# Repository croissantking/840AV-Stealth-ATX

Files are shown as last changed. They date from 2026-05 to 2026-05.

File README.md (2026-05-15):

$\color{#FF0000}{IMPORTANT!}$ <b>Working with switching power supplies involves dangerous, potentially lethal voltages, even when the device is disconnected from mains power. Improper handling can result in serious injury or death.

This repository provides Gerber files and related materials in good faith to the Macintosh hobby community, without any warranty or guarantee of any kind, including safety, reliability, or fitness for any particular purpose.

This design has not been safety-certified or fully validated under all operating conditions.

By using this material, you explicitly agree that:

- You assume all risk and responsibility for construction, modification, and use
- The author is not liable for any damage, injury, or death resulting from use or misuse
- You will only proceed if you are qualified and understand high-voltage electronics safety

If you are not experienced with mains-powered or high-voltage electronics, do not attempt to use this material.</b>

<b>Introduction and Outline</b>
-
This two-layer 'ATX Conversion Board' PCB enables you rebuild a failed Delta SMP-220DB Power Supply, found in your Apple Macintosh Quadra 800/840AV or Power Macintosh 8100, with easily obtainable second hand parts.

Front

The PCB replicates the exact dimensions of the Delta's lower PCB, securing to the chassis just as the original. It's designed to have the internals of one of the following Seasonic-based ATX power supplies stood off above it as a mezzanine board:

- Antec EarthWatts EA-380 / EA-430 / EA-500 (without 'D' suffix)
- Seasonic SS-350ET / SS-400ET / SS-500ET (ES suffix also OK)
- Seasonic S12-II 500W

The PCBs in these PSUs are all the same and are labelled ATX400W REV:A5. Some of the components may be slightly different based on the output rating.

If you want, you can modify the Gerbers to fit the mounting locations of your own chosen PSU. You can also drill holes into the board but note that a new connection should be made to the ground plane from each of the new standoff locations if doing this.

The design reuses the Delta SMP-220DB AC inlet board, and replicates both the original monitor passthrough power relay and fan speed control logic for authentic behaviour.

The 20/24 pin ATX harness is intended to be cut short and looped into the +12V, GND, -12V, +5V, PS_ON and +5VSB vias seen at the top of the new PCB. This is so a soft power inverter can be integrated, and also allows the original modular Mac PSU connector to be fitted in its original location.

BOM
-
Please see <a href="https://github.com/croissantking/840AV-Stealth-ATX/blob/main/BOM.csv" target="_blank" rel="noopener noreferrer">BOM.csv</a> for a parts list.

A Digikey cart is available here: https://www.digikey.co.uk/en/mylists/list/5MLRWHWYBX

Ordering
-
Simply download the Gerbers.zip file and then upload this to JLCPCB. Pick and Place files are available for the SMD parts, if desired.

Assembly
-
Here are the steps needed to assemble your rebuilt power supply. Note that I'm working with a slightly different pre-release board layout.

key

Once you have the bare Conversion Board PCB in your hands, decide if you'll be populating the fan circuit and the CRT relay as shown in the key above. Both circuits are optional. If you are not populating the fan control circuit then your fan should be connected to the ATX PCB. The through hole parts should be taken from the original Delta PSU (apart from the fan header), while SMDs should be newly obtained.

To install the AC inlet connector, either re-use the one from the original PSU or purchase a new one.

Circuits2

In this corner you'll install the 22-way MiniFit Jr Connector (you can bring this from the old board or purchase new), trimming off the mounting flange on one side in order to make way for a metal standoff. You'll also install a small capacitor and inverter for the soft power circuit.



Detach this little washer-type part from the original PCB and solder it here.

populated

Now that the Conversion Board is populated you can fit the 4x standoffs. Place the ATX PCB on top and loosely screw it down with just the two standoffs marked '1' and '2' nearest the lower edge.



From the other side, you can start to trim the wires of your 20/24-pin ATX connector harness to the correct length to connect to the lower PCB. +12V, GND, -12V, +5V, PS_ON and +5VSB are needed; the rest can be shortened and insulated or desoldered as you wish. Hinge the ATX PCB upwards in order to get better access to solder.

You should cut back and insulate (or desolder) any drive connectors you don't need; the remaining ones will feed through the Delta housing circular cutout.



Here, all the connections have been successfully made, and the ATX PCB has been fully screwed down. 

live-neutral

Turn the assembly around again, and solder two short wires (live and neutral) from the Conversion Board to the ATX PCB. These should be at least 18AWG and preferably 16AWG.



The full assembly can now be installed in your Delta housing, and the AC inlet board plugged in to the Conversion Board.

$\color{#FF0000}{IMPORTANT!}$ The two large left-hand heatsinks on the ATX board have a high voltage when the unit is powered up (and for some time after power is disconnected) which will give you a nasty shock if you touch them. Please be extra careful.



Make sure to insulate the ferrite ring with kapton tape (or similar) so that it does not accidentally short out the exposed solder joints on the back of the inlet board.

fan-rewire

You can re-use the original 120mm fan or install a modern replacement (e.g. Noctua). In my build I opted to re-use the original but it needed a longer cable with a three-pin connector for my Conversion Board's new header. So I peeled back the sticker over the motor to expose the solder points and replace the cable.



The cable was now long enough to reach the new header on the Conversion Board, with plenty of slack for ease of installation.


Here is the PSU fully assembled and ready to use.

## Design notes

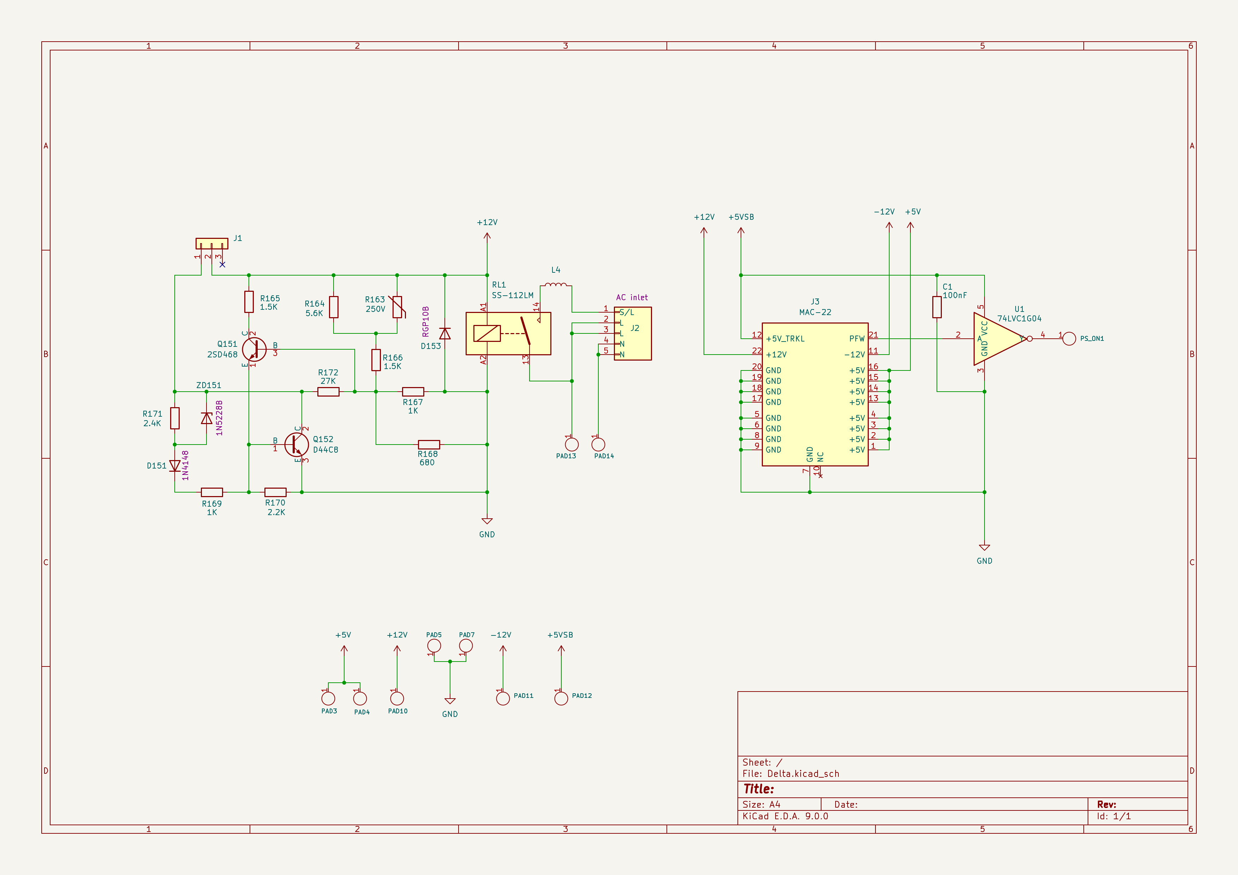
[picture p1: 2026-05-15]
Preview/Delta-schematics.jpg

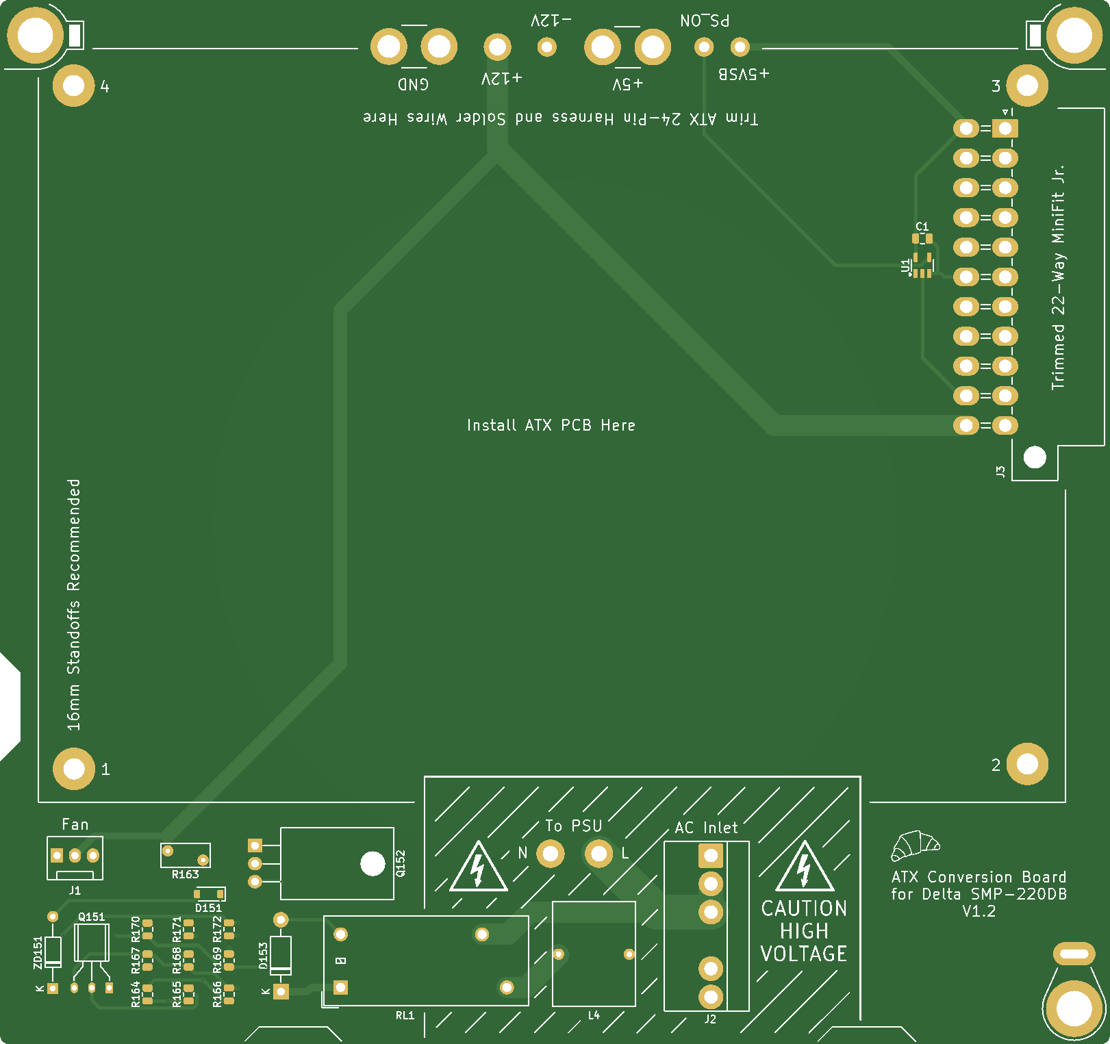
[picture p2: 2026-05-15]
Preview/Front.png

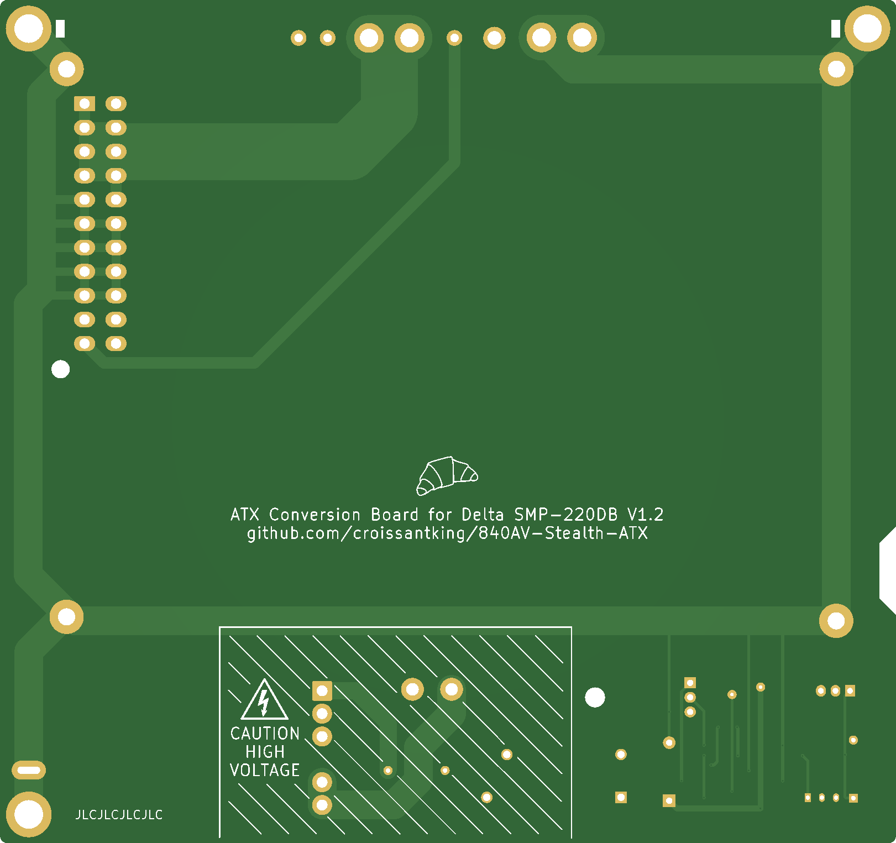
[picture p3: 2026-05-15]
Preview/Back.png

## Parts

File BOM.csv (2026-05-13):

Item | Qty | Reference(s) | Value | Size (Imperial) | P/N | URL
Capacitor | 1 | C1 | 100nF | 0805 | CC0805KRX7R9BB104 | https://www.digikey.co.uk/short/rhqt2bb8
Inverter | 1 | U1 | 74LVC1G04 | SOT-23-5 | SN74LVC1G04DBVR | https://www.digikey.co.uk/short/q94n5n4v
Varistor | 1 | R163 | 250V |  |  | Obsolete, reuse old part
Resistor | 1 | R164 | 5.6K | 0805 | RC0805FR-075K6L | https://www.digikey.co.uk/short/3hchtvn2
Resistor | 2 | R165, R166 | 1.5K | 0805 | RC0805FR-071K5L | https://www.digikey.co.uk/short/47733rr1
Resistor | 2 | R167, R169 | 1K | 0805 | RC0805FR-071KL | https://www.digikey.co.uk/short/3r7cmt8z
Resistor | 1 | R168 | 680 | 0805 | RC0805JR-07680RL | https://www.digikey.co.uk/short/p1r5pjzt
Resistor | 1 | R170 | 2.2K | 0805 | RC0805JR-072K2L | https://www.digikey.co.uk/short/30m97n75
Resistor | 1 | R171 | 2.4K | 0805 | RC0805JR-072K4L | https://www.digikey.co.uk/short/4pn84b8b
Resistor | 1 | R172 | 27K | 0805 | RC0805FR-0727KL | https://www.digikey.co.uk/short/m2709928
Relay | 1 | RL1 | OMIT-SS-112LM |  |  | Obsolete, reuse old part
Zener Diode | 1 | ZD151 | 1N5228B | DO-35 |  | https://www.digikey.co.uk/short/841nhv9d
Diode | 1 | D151 | 1N4148 | SOD-123 | 1N4148W-7-F | https://www.digikey.co.uk/short/0tb77nc3
Diode | 1 | D153 | RGP10B | DO-41 |  | https://www.digikey.co.uk/short/dnzptpbv
Transistor | 1 | Q151 | 2SD468 | TO-92 |  | Obsolete, reuse old part
Transistor | 1 | Q152 | D44C8 | TO-220 |  | Obsolete, reuse old part
Connector | 1 | J1 | Molex KK100, 6373 |  | 22-23-2033 | https://www.digikey.co.uk/short/rzfj2mbw
Connector | 1 | J2 | Molex KK396, 5273 |  | 09-65-2068 | https://www.digikey.co.uk/short/9mqpdqwd
Connector | 1 | J3 | Molex Mini-Fit Jr |  | 39-29-1227 | https://www.digikey.co.uk/short/t949vm2z
Inductor | 1 | L4 |  |  |  | Obsolete, reuse old part

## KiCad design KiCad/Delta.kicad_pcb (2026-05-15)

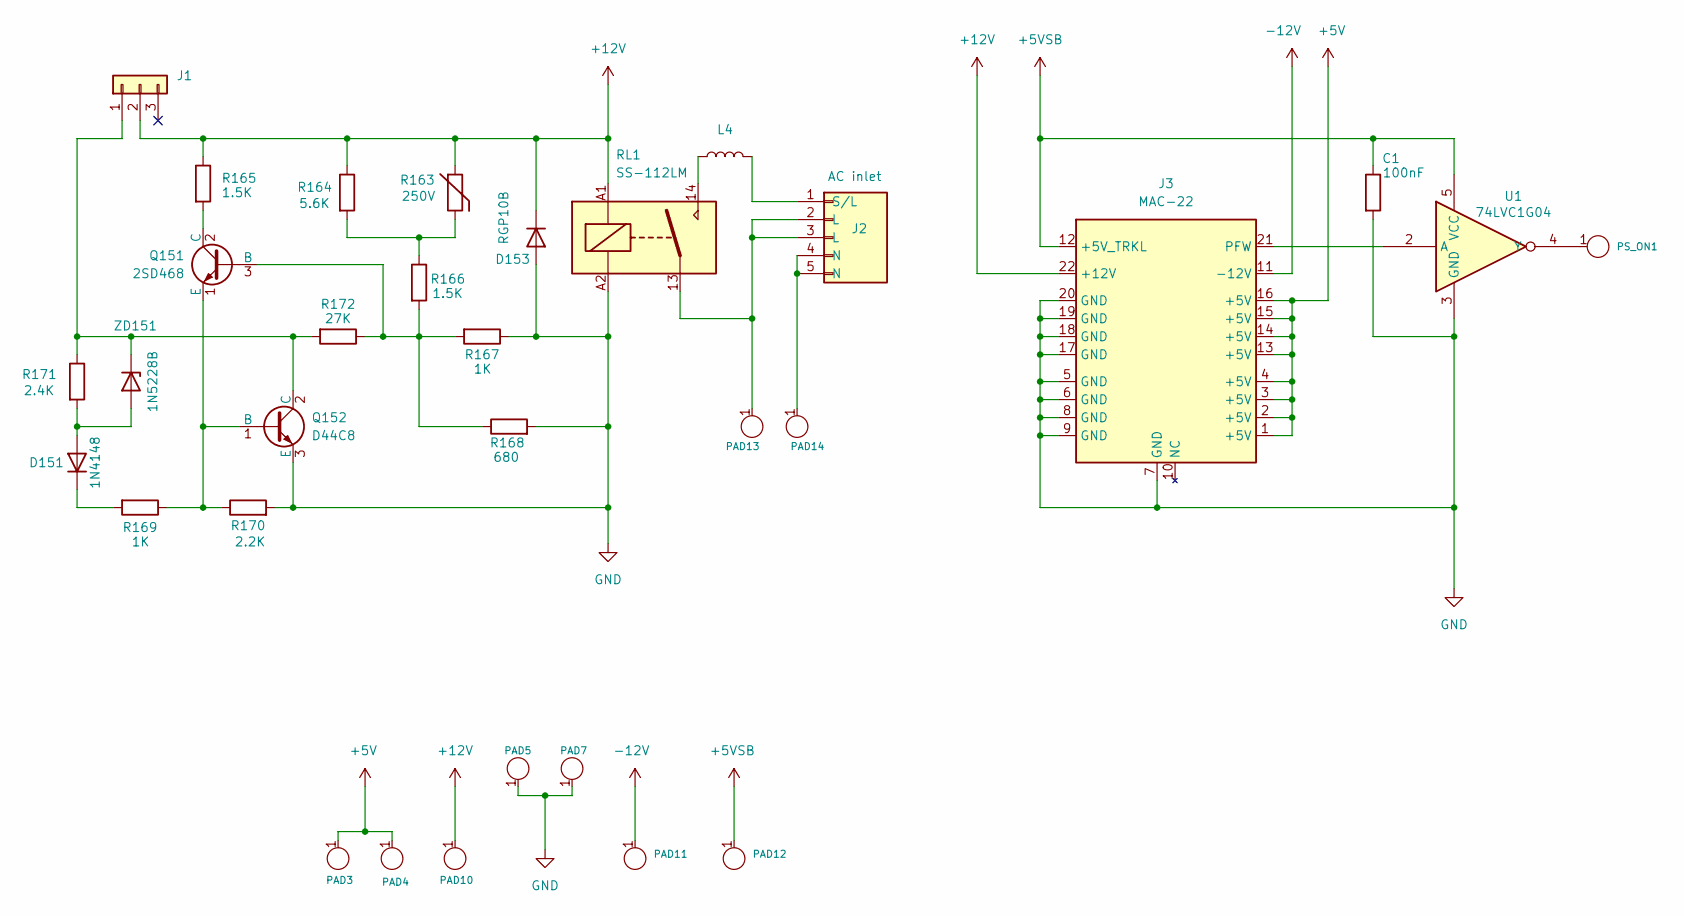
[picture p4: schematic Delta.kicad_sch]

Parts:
C1: 100nF; C_0805_2012Metric; LCSC C49678
D151: D_SOD-123; LCSC C83528
D153: D_DO-41_SOD81_P10.16mm_Horizontal
J1: Conn_01x03; FanPinHeader_1x03_P2.54mm_Vertical
J2: Conn_01x05; Pete_840AV_1x05_P4.00mm_Horizontal
J3: MAC-22; Molex_Mini-Fit_Jr_5569-22A1_2x11_P4.20mm_Horizontal_PETER
L4: L; L_Radial_L8.0mm_W8.0mm_P5.00mm_Neosid_SD8_PETER
PAD3, PAD4, PAD5, PAD7: SinglePad_PSU_Peter
PAD10: SinglePad_PSU_Peter_6_+12V
PAD11, PAD12: SinglePad_PSU_Peter_3_5VSB_-12V_PSON
PAD13, PAD14: SinglePad_PSU_Peter_1
PS_ON1: SinglePad_PSU_Peter_3_5VSB_-12V_PSON
Q151: 2SD468; TO-92_Inline_W4.0mm_Horizontal_FlatSideDown_PETER
Q152: D44C8; TO-220-3_Horizontal_TabDown
R163: 250V; RV_Disc_D7mm_W3.4mm_P5mm
R164: 5.6K; R_0805_2012Metric; LCSC C114538
R165, R166: 1.5K; R_0805_2012Metric; LCSC C114555
R167, R169: 1K; R_0805_2012Metric; LCSC C95781
R168: 680; R_0805_2012Metric; LCSC C93658
R170: 2.2K; R_0805_2012Metric; LCSC C114237
R171: 2.4K; R_0805_2012Metric; LCSC C114236
R172: 27K; R_0805_2012Metric; LCSC C114533
RL1: SS-112LM; Relay_SPST_Omron_G2RL-1A
U1: 74LVC1G04; SOT-23-5; LCSC C7827
ZD151: D_DO-35_SOD27_P10.16mm_Horizontal

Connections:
+5V: J3.1 (+5V), J3.2 (+5V), J3.3 (+5V), J3.4 (+5V), J3.13 (+5V), J3.14 (+5V), J3.15 (+5V), J3.16 (+5V), PAD3.1, PAD4.1
+5VSB: C1.1, J3.12 (+5V_TRKL), PAD12.1, U1.5 (VCC)
+12V: D153.1 (K), J1.2, J3.22 (+12V), PAD10.1, R163.1, R164.1, R165.1, RL1.A1
-12V: J3.11 (-12V), PAD11.1
GND: C1.2, D153.2 (A), J3.5 (GND), J3.6 (GND), J3.7 (GND), J3.8 (GND), J3.9 (GND), J3.17 (GND), J3.18 (GND), J3.19 (GND), J3.20 (GND), PAD5.1, PAD7.1, Q152.3 (E), R167.1, R168.2, R170.2, RL1.A2, U1.3 (GND)
unnamed: D151.2 (A), R171.2, ZD151.2 (A)
unnamed: D151.1 (K), R169.2
unnamed: J1.1, Q152.2 (C), R171.1, R172.2, ZD151.1 (K)
unnamed: J2.1 (CRT_L), L4.2
unnamed: J2.2 (L), J2.3 (L), PAD13.1, RL1.13
unnamed: J2.4 (N), J2.5 (N), PAD14.1
unnamed: J3.21 (PFW), U1.2 (A)
unnamed: L4.1, RL1.14
unnamed: Q151.3 (B), R166.2, R167.2, R168.1, R172.1
unnamed: Q151.2 (C), R165.2
unnamed: Q151.1 (E), Q152.1 (B), R169.1, R170.1
unnamed: R163.2, R164.2, R166.1
unnamed: PS_ON1.1, U1.4 (Y)

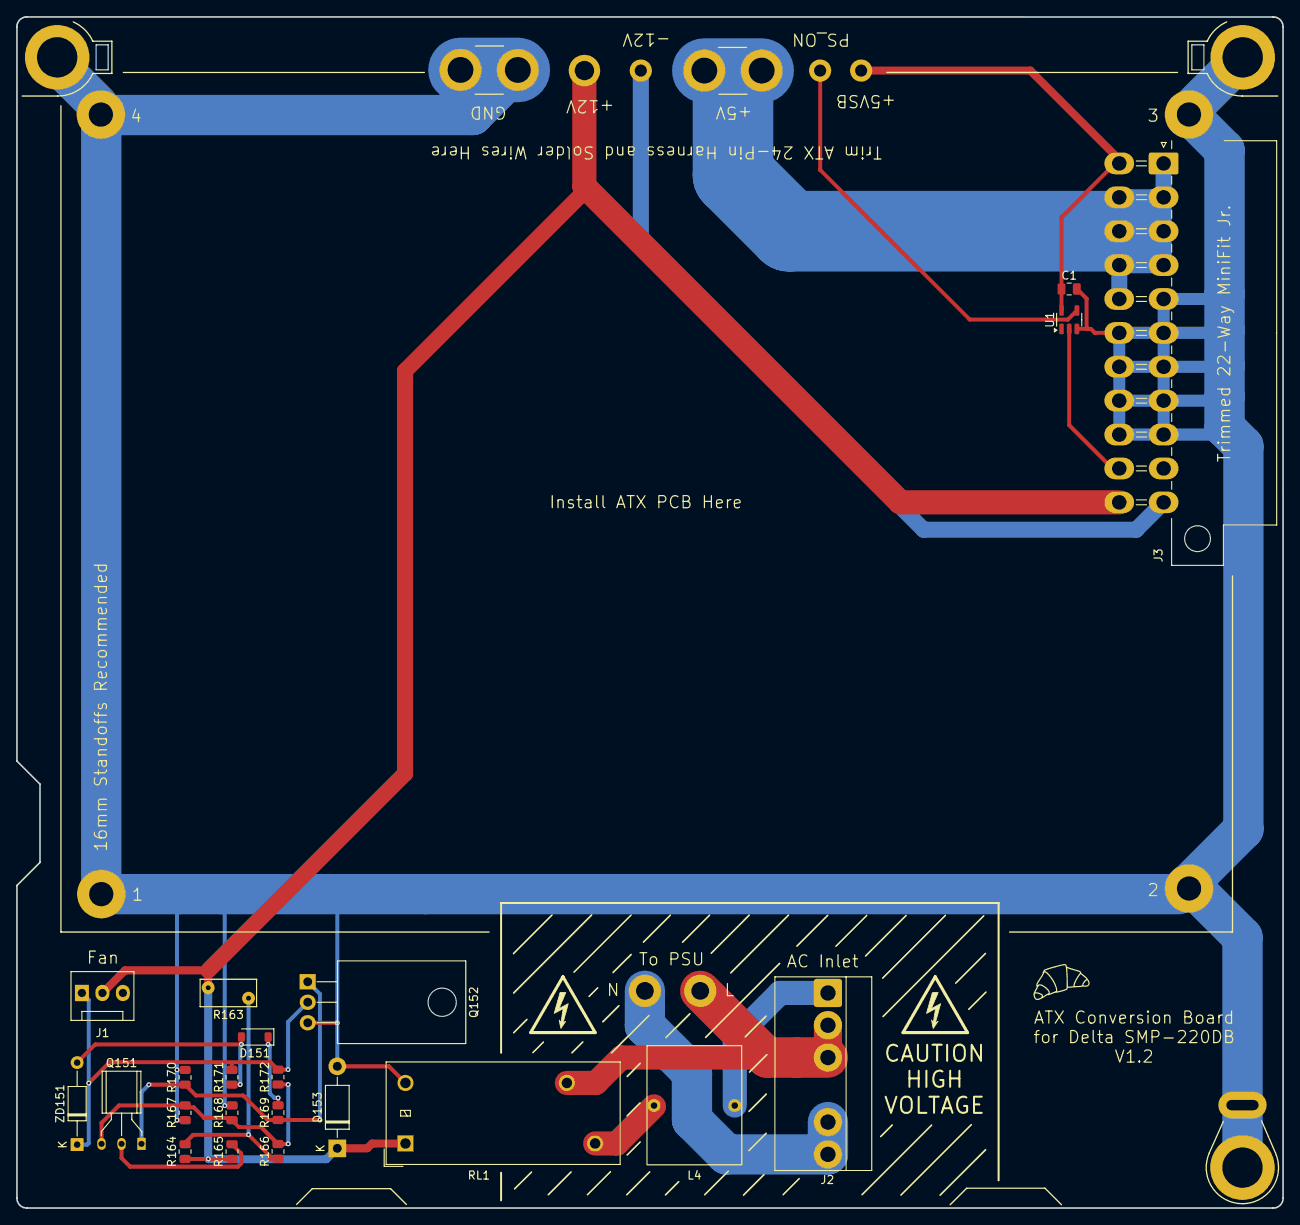
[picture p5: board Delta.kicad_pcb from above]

Board: 2 copper layers, 156.9 x 147.6 mm, 32 parts (0 on the bottom side), 18 nets.

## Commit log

2026-04-27 Update README.md
    Added PCB render
2026-05-14 Add files via upload
    Small adjustments to silkscreen for final release. I am still calling this V1.1.
2026-05-14 Add files via upload
    Edited these files to remove designators that aren't needed - we only need to place SMD parts.
    [delta-toolkit_bom.csv, delta-toolkit_positions.csv]
2026-05-14 Add files via upload
    Small silkscreen tweaks ahead of initial release.
    [Delta-B_Cu.gbl, Delta-B_Mask.gbs, Delta-B_Paste.gbp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]
2026-05-14 Add files via upload
    Version 1.2 of the gerbers focuses on some changes to safety - layout and warnings have been improved
2026-05-14 Add files via upload
    V1.2
    [Delta-B_Cu.gbl, Delta-B_Mask.gbs, Delta-B_Paste.gbp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]
